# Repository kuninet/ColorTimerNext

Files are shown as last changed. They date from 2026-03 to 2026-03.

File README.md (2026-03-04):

# ColorTimer Next

ColorTimer の次期バージョンプロジェクトです。
IoTデバイス (ESP32) のボタンを押すことで、作業の開始・終了をクラウド（AWS）へ送信し、Webアプリでその履歴や統計情報を確認することができます。

## プロジェクトの目的と要件

本プロジェクトは以下の要件・前提のもとで開発を進めています。
詳細な機能要件、非機能要件については [要件.md](./docs/要件.md) を参照してください。

* **シンプルな実装**: テスト的に1台の機器からAWSにデータを送ることを想定しており、エッジ側もクラウド側も限りなくシンプルな設計・実装を行います。
* **限りなく無料枠**: 個人利用のためのプロジェクトであり、AWSの利用についてはAWS無料枠（Always Free / 12ヶ月無料枠）に全て収めることを目標としています。
* **オープンソース**: 本プロジェクトはオープンソース（OSS）として公開・管理します。そのため、シークレットや認証情報はコードに直書きせず、安全に管理する仕組みを取り入れています。
* **AIエージェントの活用**: 機能開発においてAIエージェントチームを活用しており、裏付け調査などのタスクには軽量なモデル（Gemini Flash等）を使用するルールで運用しています。

## リポジトリ構成 (予定)

* `/edge` : ESP32用プロジェクト（PlatformIOなどを用いたエッジ側のコード）
* `/backend` : AWSリソース構築用（AWS SAM / CDKなど構成）
* `/frontend` : Webアプリケーション（SPA等）

## ライセンス

[MIT License](LICENSE) (予定)

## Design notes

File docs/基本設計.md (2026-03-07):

# ColorTimer Next 基本設計

本ドキュメントでは、ColorTimer Nextプロジェクトのシステム全体像、インターフェース、データ構造について定義します。

## 1. システムアーキテクチャ構成
### 1.1 全体構成図 (概念)
```mermaid
flowchart LR
    A[ESP32 エッジデバイス]
    B[AWS API Gateway]
    C[AWS Lambda]
    D[(Amazon DynamoDB)]
    E[Webブラウザ<br/>PC/スマホ]
    F[S3 / CloudFront]

    A -- "Wi-Fi Manager<br/>(初期設定)" --> A
    A -- "HTTP POST<br/>(開始/終了)" --> B
    B --> C
    C -- "サーバー時刻付与" --> D
    
    F -- "SPA配信<br/>(Basic認証)" --> E
    E -- "HTTP GET<br/>(履歴取得)" --> B
```

### 1.2 各コンポーネントの役割
* **エッジ側 (ESP32-WROOM-32)**
  * **設定管理**: `WiFiManager` により初回起動時にAPになりブラウザから設定を行う。また、デバイスの**ボタンを押したまま電源を入れる（リセットする）**ことで、すべての設定（Wi-Fi、API情報等）を消去して工場出荷状態に戻す機能を実装する。
  * **状態遷移とUI**: ボタン押下をトリガーに「開始」「終了」状態を切り替え、OLEDへの状態表示、色LEDの切り替え、ブザー鳴動を行う。
  * **通信**: ステータス変更時にクラウドへ HTTPリクエスト を送信。エラー時はOLEDにエラー通知を行う。

* **クラウド側 (AWS バックエンド)**
  * **API Gateway**: データの受信用とWebアプリからの取得用の口を用意し、エッジからのリクエストはAPIキーで保護する（REST API と API Key の構成）。
  * **Lambda**: エッジからのリクエストを受け取り、**受信時のサーバー時刻**を付与してDynamoDBへ保存する。また、Webアプリからの履歴取得要求に対してDynamoDBからデータを取得し返却する。
  * **DynamoDB**: 時系列データとして安価に永続化する。

* **フロントエンド (Webアプリ)**
  * **アーキテクチャ**: React等のSPA (Single Page Application) をS3に配置し、CloudFront経由で配信する。
  * **認証**: CloudFront Functionsを用いたBasic認証でページへのアクセスを保護。
  * **機能**: API Gateway経由でLambdaからデータを取得し、作業履歴一覧および統計（週次・月次等）を表示する。

---

## 2. インターフェース設計 (REST API)

### 2.1 データ受信用 API (ESP32 -> AWS)
* **Endpoint**: `POST /api/logs`
* **認証**: HTTP Header `x-api-key: <ESP32に設定したAPIキー>`
* **Request Body (JSON)**:
  ```json
  {
    "device_id": "esp32-timer-01",
    "action": "start"  // "start" または "end"
  }
  ```
* **Response**:
  * 成功時: `200 OK`
  * 失敗時: `400 Bad Request`, `403 Forbidden`, `500 Internal Server Error`

### 2.2 データ取得用 API (Web App -> AWS)
* **Endpoint**: `GET /api/logs?device_id={device_id}&start_date={YYYY-MM-DD}&end_date={YYYY-MM-DD}`
* **認証**: Webアプリ側のセッションや事前発行トークン（Basic認証環境下での簡易なもの）を想定。
* **Response Body (JSON)**:
  ```json
  [
    {
      "timestamp": "2026-03-04T10:00:00Z",
      "action": "start"
    },
    ...
  ]
  ```

---

## 3. データベース設計 (DynamoDB テーブル定義)

永続化や集計のしやすさを考慮し、ログテーブルを以下のように設計する。
無料枠(25WCU/25RCU)に収めるため、プロビジョニングモードでミニマム構成とする想定。

| 項目論理名 | 項目物理名  | データ型 | キー設定 | 説明 |
| :--- | :--- | :--- | :--- | :--- |
| デバイスID | `DeviceId`  | String | **Partition Key (PK)** | リクエスト送信元のデバイスの識別子 |
| 送信日時 | `Timestamp` | String | **Sort Key (SK)** | ISO8601拡張形式（例: `2026-03-04T10:00:00.000Z`）。Lambdaで付与 |
| アクション | `Action` | String | - | "start" または "end" |
| 有効期限 | `ExpireAt`  | Number | (TTL属性) | DynamoDB TTL 用の Unix epoch 秒。Receiver Lambda で `LOG_RETENTION_DAYS` を元に付与する。 |

---

## 4. ハードウェア設計 (エッジデバイス)

本プロジェクトのエッジデバイスはメモリ・通信性能の安定性と将来の拡張性を考慮し、**ESP32-WROOM-32E** を採用します。

### 4.1 構成部品 (BOM)

| 部品名 | 仕様・想定パーツ | 数量 | 用途 |
| :--- | :--- | :--- | :--- |
| MCUボード | ESP32-WROOM-32E 開発ボード | 1 | メイン制御、Wi-Fi通信、HTTPSリクエスト通信 |
| ディスプレイ | 0.96インチ I2C OLED (SSD1306等) | 1 | 各種状態や通信エラーの表示 |
| フルカラーLED  | 砲弾型等RGB LED（または赤・青の単色LED2個） | 1 | 稼働状態の可視化。指定された「赤」「青」の点灯・点滅に使用 |
| 抵抗 | 330Ω（LED用）、10kΩ（スイッチ用） | 適宜 | 電流制限、外部プルアップ（必要に応じて）等 |
| タクトスイッチ | 汎用タクトスイッチ | 1 | 作業の「開始」「終了」を行うトリガーボタン |
| 圧電ブザー | パッシブブザー または アクティブブザー | 1 | 状態変更時（開始・終了・タイムアウト）の音通知 |

### 4.2 ピンアサインメント (GPIO割り当て案)

ESP32内でI2Cや各種出力として標準的かつ安全に利用可能な通信ピン・GPIOピンを割り当てます。

| コンポーネント | ポート/役割 | ESP32 GPIO  | 備考 |
| :--- | :--- | :--- | :--- |
| **OLED (I2C)** | SDA | **GPIO 21** | ESP32の標準I2Cデータピン |
| | SCL | **GPIO 22** | ESP32の標準I2Cクロックピン |
| **LED** | 赤色 (停止中) | **GPIO 25** | 出力利用に標準的で安全なGPIO |
| | 青色 (作業中) | **GPIO 26** | 出力利用に標準的で安全なGPIO |
| **ブザー** | 制御用 (PWM等)  | **GPIO 27** | 自由に出力として使えるGPIO |
| **スイッチ** | トリガー (入力) | **GPIO 33** | プログラム側で内部プルアップ(`INPUT_PULLUP`)を有効化して使用 |

> **Note**: 本表のアサインメントに従い、別途 `hardware/` などのディレクトリにてKiCadを使った物理的な基板設計・回路図作成をユーザー側で実施いただく進め方となります。

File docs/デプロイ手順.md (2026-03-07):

# デプロイ・構築手順

本ドキュメントでは、ColorTimer Nextプロジェクトの各コンポーネント（クラウド基盤・Webアプリ・エッジデバイス）のビルドから実環境へのデプロイ（書き込み）手順を記述します。
開発機材として、macOS および Windows 双方での操作を想定しています。

---

## 1. クラウド基盤のデプロイ (AWS SAM もしくは CDK想定)
**構成**: API Gateway + Lambda + DynamoDB

### 前提条件
- [AWS CLI](https://aws.amazon.com/jp/cli/) およびデプロイツール（[AWS SAM CLI](https://docs.aws.amazon.com/serverless-application-model/latest/developerguide/install-sam-cli.html) または Node.js + AWS CDK）がインストールされていること。
- `aws configure` コマンドで対象AWSアカウントのCredentials設定が完了していること。

### デプロイコマンド (SAM CLIの例)
```bash
# プロジェクトのルートディレクトリにいることを確認

# 推奨: 補助スクリプトでデプロイ
./scripts/aws/deploy-backend.sh

# ログ保持日数を変更する場合
./scripts/aws/deploy-backend.sh 30

# 環境変数で指定することも可能
LOG_RETENTION_DAYS=30 ./scripts/aws/deploy-backend.sh
```

手動で実行する場合:

```bash
cd backend
sam build
sam deploy --guided
sam deploy --parameter-overrides \
  BasicAuthValidAuths='["Basic <base64(username:password)>"]' \
  LogRetentionDays=365
```

---

## 2. Webアプリのデプロイ (フロントエンド)
**構成**: S3 (静的ホスティング) + CloudFront

### 前提条件
- Node.js (v18以降推奨) がインストールされていること。
- クラウド基盤側でデプロイされた S3バケット名 と CloudFrontの Distribution ID を確認していること。

### デプロイコマンド
作成済みの自動デプロイスクリプトを使用します。

```bash
# プロジェクトのルートディレクトリにいることを確認
# (フロントエンドのビルド、S3同期、CloudFrontのキャッシュクリアを自動で行います)
./scripts/aws/deploy-frontend.sh
```
*(※初回は backend 側がデプロイされ、S3バケットとCloudFrontディストリビューションが作成されている必要があります。)*

---

## 3. エッジデバイスの書き込み (ESP32)
**構成**: ESP32-WROOM-32 (PlatformIO での開発を想定)

### 前提条件
- VSCode および [PlatformIO IDE 拡張機能](https://platformio.org/install/ide?install=vscode) がインストールされていること。（CLI版の `pio` コマンドでも可）
- ESP32とPCがUSBケーブル(データ通信対応)で接続されていること。
- **Windows特有**: ESP32のUSBシリアル変換ドライバ (CP210x等) がインストールされ、デバイスマネージャーでCOMポートとして認識されていること。
- HTTPS の証明書検証のため、起動後に NTP で時刻同期できるインターネット接続があること。

### デプロイコマンド (PlatformIO Core CLI の例)
VSCode上からPlatformIOの「Upload」ボタン（右下の矢印アイコン）を押すのが最も簡単ですが、CLIで行う場合は以下となります。

```bash
# プロジェクトのエッジ側ディレクトリへ移動
cd edge

# 依存ライブラリのインストール・ビルド
pio run

# ESP32実機への書き込み
pio run -target upload

# (オプション) シリアルモニタを開いて動作確認・ログ確認
pio device monitor
```
- ※Windowsでは対象ポートが複数ある場合、上記コマンドで自動で認識されないことがあります。その場合は `pio run -t upload --upload-port COM3` のように明示的に指定してください。
- ※macOSでは `--upload-port /dev/cu.usbserial-*` のように指定できます。

---

## 4. 運用保守用スクリプトの実行（CloudFront Basic認証管理）
CloudFront Functions を利用したBasic認証のID/PWを管理・更新するためのスクリプトです。
認証情報は `backend/basic-auth-users.local.json` に保存され、このファイルは git 管理対象外です。

```bash
# プロジェクトのルートディレクトリにいることを確認

# ユーザー一覧に追加・更新する場合
./scripts/aws/manage-basic-auth.sh add <username> <password>

# ユーザーを削除する場合
./scripts/aws/manage-basic-auth.sh remove <username>

# 現在のユーザー一覧を確認する場合
./scripts/aws/manage-basic-auth.sh list

# SAM Parameter 用の JSON 配列だけ出力する場合
./scripts/aws/manage-basic-auth.sh print-parameter

# スクリプト実行後は backend デプロイスクリプトを使うと反映しやすいです
./scripts/aws/deploy-backend.sh

# 保持日数も同時に変える場合
./scripts/aws/deploy-backend.sh 30
```

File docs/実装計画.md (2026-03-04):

# 実装計画 (Issue分割予定一覧)

システムの構築を「クラウド基盤」「エッジ」「フロントエンド」の3つのフェーズに分け、以下の粒度でGitHub Issueを作成し、順次実装とPR（Pull Request）を進める計画とします。

## Phase 1: クラウド基盤 (AWS バックエンド)
このフェーズでは、AWS上にAPIとデータベースを構築し、ローカルやPostman等で単体テストが通る状態を目指します。

* **Issue 1**: [Infra] AWSバックエンドリソースのコード化（SAM等）および DynamoDBテーブルの作成
* **Issue 2**: [Backend] ステータスデータ受信用機能 (API Gateway + Lambda) の実装とローカル単体テスト・モックテストの作成
* **Issue 3**: [Backend] データ取得用API (API Gateway + Lambda) の実装と単体テスト・CORS設定

## Phase 2: エッジデバイス (ESP32)
APIのインターフェースが固まった状態で、実際にデバイスからの通信とハードウェア制御を組み込みます。

* **Issue 4**: [Edge] PlatformIOプロジェクトの初期化と、`WiFiManager` を用いたAPモード・ブラウザ設定(Wi-Fi・APIキー・タイムアウト等)の実装
* **Issue 5**: [Edge] ハードウェア制御 (物理ボタンによる状態切替、フルカラーLED制御、ブザー鳴動、OLEDディスプレイへの状態表示) の実装
* **Issue 6**: [Edge] AWS APIへのHTTP POST送信処理と、エラー時（未接続・送信失敗）のOLEDエラー表示・ハンドリングの実装

## Phase 3: フロントエンド (Webアプリケーション)
クラウドのAPIからデータを取り出し、描画と集計を行うSPAを構築します。

* **Issue 7**: [Frontend] React(Vite等)プロジェクトの初期化と、S3+CloudFrontへの静的デプロイパイプライン（手動コマンド等）の準備
* **Issue 8**: [Frontend/Infra] CloudFront Functions を用いたサイト全体のBasic認証の実装と、簡易なID/PW管理用シェルスクリプトの作成
* **Issue 9**: [Frontend] 作業履歴・ログの一覧表示画面（API連携）の実装
* **Issue 10**: [Frontend] 作業ログに基づく週次・月次の稼働状況・統計表示画面の実装

---
本計画に基づいて順番にIssueを作成し、実装・レビュー（ユーザー確認）・マージのサイクルを回して開発を進めます。

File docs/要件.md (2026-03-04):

# ColorTimer Next 要件

## 概要
* ColorTimerの次期バージョンを開発する。
* **プロジェクトの前提**
  * 1台の機器からテスト的にAWSにデータを送ることを想定。
  * エッジ側もクラウド側も**限りなくシンプルな実装**にする。
  * AWSの利用料金は**限りなく無料枠に納める**ことを目標にする。
  * プロジェクトは**オープンソースハードウェア/ソフトウェアとしてGitHubで公開・管理**する。シークレット情報の取り扱いには注意する。
  * 【エージェント開発ルール】調査などのタスクメンバ作業は「Gemini Flash」などの軽量モデルで実施する（今後の他プロジェクトも共通）。

## 要件
### 機能要件
* エッジ側
  * Color Timerのエッジ部分はESP32-WROOM-32を使用する。
    * [[116108]ESP32-WROOM-32Eマイコンボード](https://akizukidenshi.com/catalog/g/g116108/)
  * トリガーボタンを押すと、「作業開始」「作業終了」をクラウドへ送信する。
  * 本体にはLED2つ装備
    * 赤LED - 作業してない
    * 青LED - 作業中(設定したタイムアウト時間が来ると点滅してお知らせ。自動終了はせず、ユーザーのボタン操作で終了イベントを送信する)
  * OLEDディスプレイに現在の状況を表示
    * 起動完了
    * 作業開始
    * 作業終了
    * タイムアウト
    * エラー（Wi-Fi未接続やAWS送信エラーが発生した場合）
  * 圧電ブザーで作業開始、タイムアウト、作業終了を通知
  * **ネットワーク接続・初期設定**: 
    * 初期起動時はマイコンがアクセスポイント(AP)として動作する。
    * PCやスマートフォンのブラウザからアクセスし、Wi-Fi設定（SSID/パスワード）や各設定値（タイムアウト値など）を設定可能にする。

* クラウド側
  * データ受信のアーキテクチャ
    * **API Gateway (HTTP API) + Lambda** 構成で受信する。（AWS IoT Core等のような複雑な証明書管理は避け、ESP32からのHTTPリクエストでシンプルに受信する）
  * 受信した「作業開始」「作業終了」の日時を永続化する。
    * クラウド側での受信時刻をタイムスタンプとする。（エッジ側では時刻を持たず、「開始」「終了」のイベント種別のみを送信する）
    * ストレージには **DynamoDB**（オンデマンド または プロビジョニング25WCU/25RCUの無料枠内）を使用する。
  * Webアプリ
    * 作業履歴の一覧表示できるようにしたい。
    * 統計表示（週次、月次の稼働状況）を見えるようにしたい。
    * ホスティングは **S3静的ホスティング + CloudFront** のSPA構成とする。

### 非機能要件
* セキュリティ対策
  * 最低限のセキュリティはかけたい。AWSにいたずらされない程度の対策をしたい。軽く機器認証はしたい。
    * API Gatewayの **APIキー** を利用して、エッジ側からのリクエストを簡易認証する。
  * Webアプリを使えるIDを限定したい。アプリID管理はあまり複雑になりすぎない程度で。
    * Cognito等の複雑な構成は避け、**CloudFront Functionsを使ったBasic認証** で保護する。
    * ※ 運用保守用として、パスワード変更やID/PW追加ができる簡易なシェルスクリプトを別途用意する。
  * **OSS対応**: 認証情報や設定値などは.env等で管理し、リポジトリには含めない。

* パフォーマンス
  * 当初は1台程度の負荷を想定。

* 可用性
  * 個人使用なので、可用性要件なし。

* コスト
  * AWSのサービスを活用するが、なるべく安価にしたい。無料枠にすべて収まるのが理想。

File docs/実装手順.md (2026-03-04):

# 実装手順

## 進め方
* githubリポジトリ(公開)を作成
* 設計文書、実装計画文書を作成して、承認を取る
* 実装計画に基づいて、githubにissueを作成して、順番に実装する
* issueが実装計画と合っているか確認して承認を取る
* issueごとにブランチを作成して実装を開始して、実装完了ごとに承認をとり、承認されたらPRを作成してマージする。
* **[追加提案]** PR作成時はIssue番号を紐付け（`Fixes #Issue番号` 等）、マージ時にIssueが自動クローズされるようにする。
* **[追加提案]** 実装の完了・マージに合わせて、システム構成や設計に変更があった場合は `README.md` や設計ドキュメントを忘れずに更新する。
* **[追加提案]** 必要に応じて、PR作成時に静的解析（Lint等）が走るCI環境（GitHub Actions等）を設定し、品質を担保する。
* **[追加提案]** クラウド側（LambdaやAPI等）の実装においては、デプロイ前にパソコン上（ローカル環境）で単体テストやモックを利用したテストを実行・検証できる設計とし、実装と並行してテストコードを作成する。

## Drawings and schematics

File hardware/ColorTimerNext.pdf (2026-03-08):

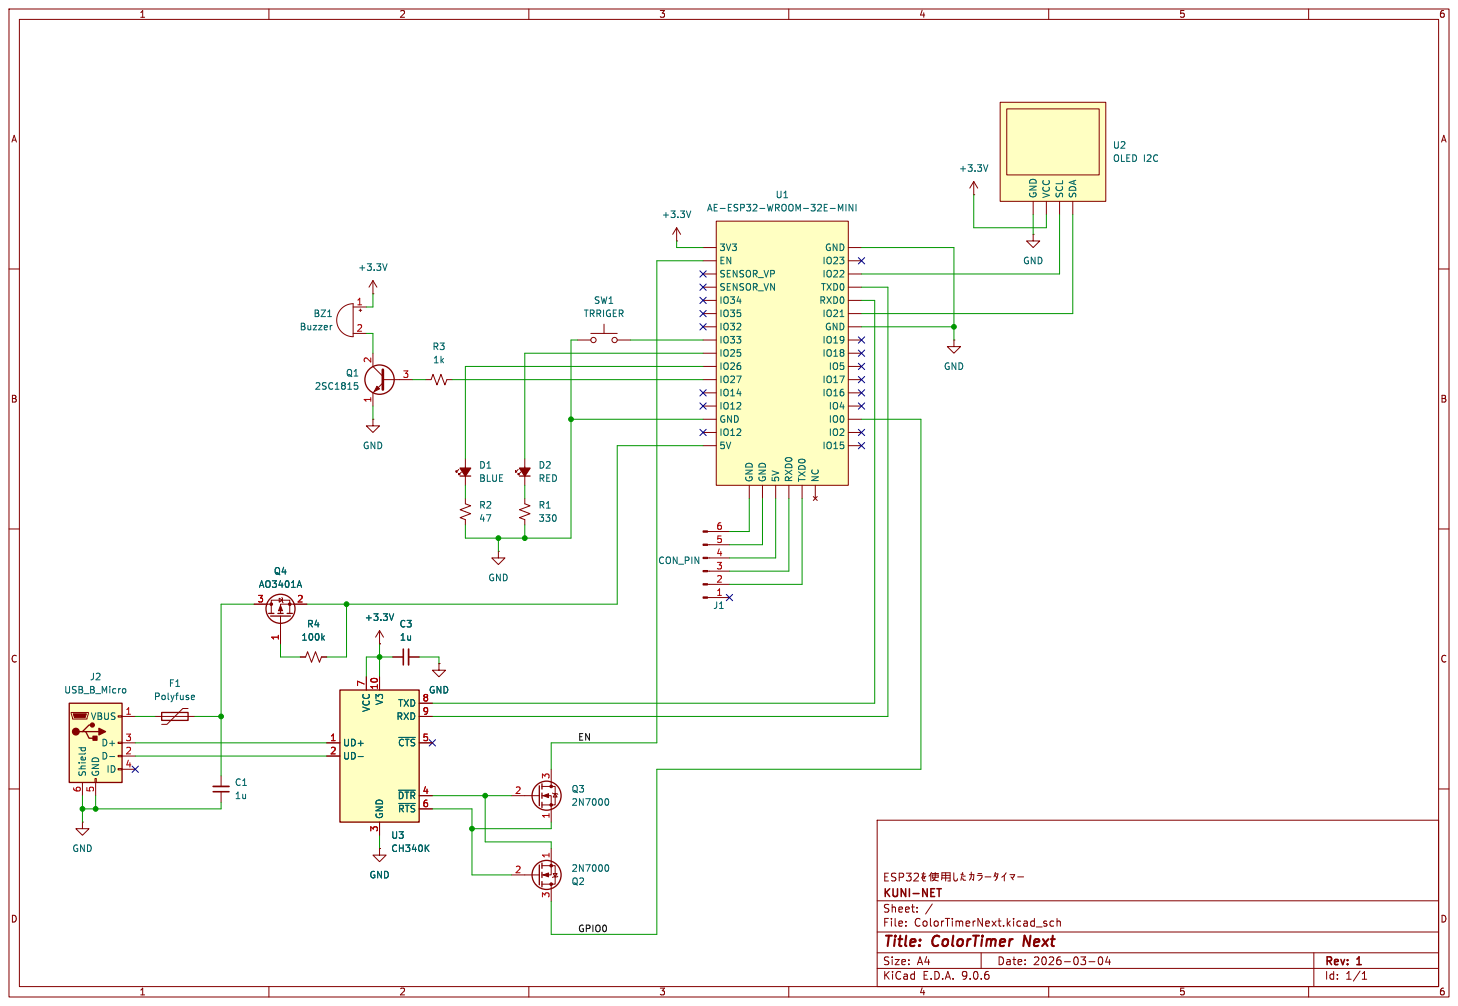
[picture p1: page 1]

3 TXD 8 RXD 9 ~{CTS}5 ~{DTR}4 ~{RTS}6 U3 CH340K GND GND VCC SCL SDA U2 OLED I2C

3 TXD 8 RXD 9 ~{CTS}5 ~{DTR}4 ~{RTS}6 +3.3V C3

Id: 1/1 Title: ColorTimer Next File: ColorTimerNext.kicad_sch Sheet: / KUNI-NET

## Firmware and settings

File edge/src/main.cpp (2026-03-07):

#include "HardwareConfig.h"
#include <Arduino.h>
#include <ArduinoJson.h>
#include <Bounce2.h>
#include <HTTPClient.h>
#include <Preferences.h>
#include <WiFiClientSecure.h>
#include <WiFiManager.h>
#include <time.h>

Preferences preferences;

// Preferencesの名前空間とキー名
const char *PREF_NAMESPACE = "colortimer";
const char *PREF_DEVICE_ID = "device_id";
const char *PREF_API_ENDPOINT = "api_endpt";
const char *PREF_API_KEY = "api_key";
const char *PREF_TIMEOUT_MIN = "timeout_min";

// メモリ保持用変数 (初期値)
char deviceId[32] = "esp32-timer-default";
char apiEndpoint[128] =
    "https://********.execute-api.ap-northeast-1.amazonaws.com/prod/api/logs";
char apiKey[64] = "your_api_key_here";
char timeoutMin[8] = "30"; // デフォルト30分

bool shouldSaveConfig = false;
bool systemTimeSynchronized = false;

const char *NTP_PRIMARY_SERVER = "time.aws.com";
const char *NTP_SECONDARY_SERVER = "pool.ntp.org";
const char *NTP_TERTIARY_SERVER = "ntp.nict.jp";
constexpr time_t MIN_VALID_UNIX_TIME = 1704067200; // 2024-01-01T00:00:00Z
constexpr unsigned long TIME_SYNC_TIMEOUT_MS = 15000;
constexpr unsigned long TIME_SYNC_POLL_INTERVAL_MS = 250;
constexpr unsigned long TLS_HANDSHAKE_TIMEOUT_SEC = 15;

// Amazon Root CA 1 for execute-api.*.amazonaws.com certificates.
const char *AWS_ROOT_CA = R"CERT(
-----BEGIN CERTIFICATE-----
MIIDQTCCAimgAwIBAgITBmyfz5m/jAo54vB4ikPmljZbyjANBgkqhkiG9w0BAQsF
ADA5MQswCQYDVQQGEwJVUzEPMA0GA1UEChMGQW1hem9uMRkwFwYDVQQDExBBbWF6
b24gUm9vdCBDQSAxMB4XDTE1MDUyNjAwMDAwMFoXDTM4MDExNzAwMDAwMFowOTEL
MAkGA1UEBhMCVVMxDzANBgNVBAoTBkFtYXpvbjEZMBcGA1UEAxMQQW1hem9uIFJv
b3QgQ0EgMTCCASIwDQYJKoZIhvcNAQEBBQADggEPADCCAQoCggEBALJ4gHHKeNXj
ca9HgFB0fW7Y14h29Jlo91ghYPl0hAEvrAIthtOgQ3pOsqTQNroBvo3bSMgHFzZM
9O6II8c+6zf1tRn4SWiw3te5djgdYZ6k/oI2peVKVuRF4fn9tBb6dNqcmzU5L/qw
IFAGbHrQgLKm+a/sRxmPUDgH3KKHOVj4utWp+UhnMJbulHheb4mjUcAwhmahRWa6
VOujw5H5SNz/0egwLX0tdHA114gk957EWW67c4cX8jJGKLhD+rcdqsq08p8kDi1L
93FcXmn/6pUCyziKrlA4b9v7LWIbxcceVOF34GfID5yHI9Y/QCB/IIDEgEw+OyQm
jgSubJrIqg0CAwEAAaNCMEAwDwYDVR0TAQH/BAUwAwEB/zAOBgNVHQ8BAf8EBAMC
AYYwHQYDVR0OBBYEFIQYzIU07LwMlJQuCFmcx7IQTgoIMA0GCSqGSIb3DQEBCwUA
A4IBAQCY8jdaQZChGsV2USggNiMOruYou6r4lK5IpDB/G/wkjUu0yKGX9rbxenDI
U5PMCCjjmCXPI6T53iHTfIUJrU6adTrCC2qJeHZERxhlbI1Bjjt/msv0tadQ1wUs
N+gDS63pYaACbvXy8MWy7Vu33PqUXHeeE6V/Uq2V8viTO96LXFvKWlJbYK8U90vv
o/ufQJVtMVT8QtPHRh8jrdkPSHCa2XV4cdFyQzR1bldZwgJcJmApzyMZFo6IQ6XU
5MsI+yMRQ+hDKXJioaldXgjUkK642M4UwtBV8ob2xJNDd2ZhwLnoQdeXeGADbkpy
rqXRfboQnoZsG4q5WTP468SQvvG5
-----END CERTIFICATE-----
)CERT";

// 稼働ステート管理
enum TimerState { STATE_STANDBY, STATE_RUNNING, STATE_TIMEOUT };
TimerState currentState = STATE_STANDBY;

// 長押し機能やタイムアウト計算用
unsigned long stateStartTime = 0;

// ボタンのデバウンス用インスタンス
Bounce debouncer = Bounce();

bool hasValidSystemTime() { return time(nullptr) >= MIN_VALID_UNIX_TIME; }

bool ensureSystemTimeSync() {
  if (systemTimeSynchronized && hasValidSystemTime()) {
    return true;
  }

  Serial.println("Synchronizing system clock for TLS validation...");
  configTime(0, 0, NTP_PRIMARY_SERVER, NTP_SECONDARY_SERVER, NTP_TERTIARY_SERVER);

  const unsigned long startedAt = millis();
  while (millis() - startedAt < TIME_SYNC_TIMEOUT_MS) {
    if (hasValidSystemTime()) {
      systemTimeSynchronized = true;
      Serial.printf("System time synchronized: %ld\n",
                    static_cast<long>(time(nullptr)));
      return true;
    }
    delay(TIME_SYNC_POLL_INTERVAL_MS);
  }

  Serial.println("Failed to synchronize system clock; TLS connection aborted.");
  return false;
}

void clearStoredSettings(WiFiManager &wm) {
  preferences.clear();
  wm.resetSettings();
}

// WiFiManagerの設定が保存された際に呼ばれるコールバック
void saveConfigCallback() {
  Serial.println("Should save config");
  shouldSaveConfig = true;
}

// API通信関数 (戻り値: 成功なら true)
bool sendLogToApi(const char *action) {
  if (WiFi.status() != WL_CONNECTED) {
    Serial.println("Error: WiFi not connected");
    return false;
  }

  if (!ensureSystemTimeSync()) {
    return false;
  }

  WiFiClientSecure *client = new WiFiClientSecure;
  if (client) {
    client->setCACert(AWS_ROOT_CA);
    client->setHandshakeTimeout(TLS_HANDSHAKE_TIMEOUT_SEC);
  } else {
    Serial.println("Failed to create secure client");
    return false;
  }

  HTTPClient https;

  Serial.print("Connecting to API: ");
  Serial.println(apiEndpoint);

  if (https.begin(*client, apiEndpoint)) {
    // APIヘッダーの追加
    https.addHeader("Content-Type", "application/json");
    https.addHeader("x-api-key", apiKey);

    // JSONペイロードの生成
    JsonDocument doc;
    doc["device_id"] = deviceId;
    doc["action"] = action;
    String requestBody;
    serializeJson(doc, requestBody);

    Serial.print("Sending POST request: ");
    Serial.println(requestBody);

    // POST送信
    int httpCode = https.POST(requestBody);

    bool success = false;
    if (httpCode > 0) {
      Serial.printf("HTTP Response code: %d\n", httpCode);
      if (httpCode == HTTP_CODE_OK || httpCode == HTTP_CODE_CREATED) {
        // String payload = https.getString();
        // Serial.println(payload);
        success = true;
      }
    } else {
      Serial.printf("HTTP Request failed, error: %s\n",
                    https.errorToString(httpCode).c_str());
    }

    https.end();
    delete client;
    return success;
  } else {
    Serial.println("Unable to connect to HTTPS endpoint");
    delete client;
    return false;
  }
}

void setup() {
  Serial.begin(115200);
  Serial.println("\n\nStarting ColorTimer Next...");

  // ハードウェアピン等の初期化 (OLED, LED, Buzzer)
  initHardware();

  // 初期化リセット用ボタンの設定とBounce2へのアタッチ
  debouncer.attach(BUTTON_PIN, INPUT_PULLUP);
  debouncer.interval(25); // 25msのデバウンス

  // Preferencesの初期化 (読み書きモード)
  preferences.begin(PREF_NAMESPACE, false);

  // WiFiManagerのインスタンス生成
  WiFiManager wm;
  wm.setSaveConfigCallback(saveConfigCallback);

  // 起動時にボタン(GPIO33)がLOW(押されている状態)なら設定を初期化する
  debouncer.update();
  if (debouncer.read() == LOW) {
    displayStatus("RESETTING", "Clearing Settings");
    Serial.println("Reset button is pressed! Clearing all settings...");
    playBeep(500);
    clearStoredSettings(wm);
    displayStatus("CLEARED", "Please Reboot.");
    Serial.println(
        "Settings cleared. Please connect to 'ColorTimer-AP' to reconfigure.");
    while (true) {
      delay(100);
    } // 停止
  }

  // フラッシュメモリからの設定読み出し
  String savedDeviceId = preferences.getString(PREF_DEVICE_ID, deviceId);
  String savedApiEndpoint =
      preferences.getString(PREF_API_ENDPOINT, apiEndpoint);
  String savedApiKey = preferences.getString(PREF_API_KEY, apiKey);
  String savedTimeoutMin = preferences.getString(PREF_TIMEOUT_MIN, timeoutMin);

  strlcpy(deviceId, savedDeviceId.c_str(), sizeof(deviceId));
  strlcpy(apiEndpoint, savedApiEndpoint.c_str(), sizeof(apiEndpoint));
  strlcpy(apiKey, savedApiKey.c_str(), sizeof(apiKey));
  strlcpy(timeoutMin, savedTimeoutMin.c_str(), sizeof(timeoutMin));

  // カスタムパラメータの設定
  WiFiManagerParameter custom_device_id("device_id", "Device ID", deviceId, 32);
  WiFiManagerParameter custom_api_endpoint("api_endpoint", "API Endpoint URL",
                                           apiEndpoint, 128);
  WiFiManagerParameter custom_api_key("api_key", "API Gateway Key", apiKey, 64);
  WiFiManagerParameter custom_timeout_min("timeout_min", "Timeout (minutes)",
                                          timeoutMin, 8);

  wm.addParameter(&custom_device_id);
  wm.addParameter(&custom_api_endpoint);
  wm.addParameter(&custom_api_key);
  wm.addParameter(&custom_timeout_min);

  displayStatus("Wi-Fi Setup", "Connecting...");

  // Wi-Fi接続の試行。接続情報がないか失敗した場合はColorTimer-APというアクセスポイントを起動する
  if (!wm.autoConnect("ColorTimer-AP", "password")) {
    displayError("Wi-Fi Failed");
    Serial.println("Failed to connect and hit timeout");
    playErrorSound();
    delay(3000);
    ESP.restart();
  }

  // 設定ポータルでSaveされた場合、新たな値をフラッシュメモリに保存
  if (shouldSaveConfig) {
    strlcpy(deviceId, custom_device_id.getValue(), sizeof(deviceId));
    strlcpy(apiEndpoint, custom_api_endpoint.getValue(), sizeof(apiEndpoint));
    strlcpy(apiKey, custom_api_key.getValue(), sizeof(apiKey));
    strlcpy(timeoutMin, custom_timeout_min.getValue(), sizeof(timeoutMin));

    preferences.putString(PREF_DEVICE_ID, deviceId);
    preferences.putString(PREF_API_ENDPOINT, apiEndpoint);
    preferences.putString(PREF_API_KEY, apiKey);
    preferences.putString(PREF_TIMEOUT_MIN, timeoutMin);

    Serial.println("Configuration saved to Preferences.");
  }

  Serial.println("\nConnected to Wi-Fi!");
  if (!ensureSystemTimeSync()) {
    Serial.println("Warning: time sync did not complete during setup.");
  }
  displayStatus("Connected!");
  playBeep(100);
  delay(100);
  playBeep(100);

  // 初期ステート: Standby
  currentState = STATE_STANDBY;
  setLedState(LED_RED); // 待機＝赤点灯
  displayStatus("STANDBY", "Ready to Start");
  displayStatus("STANDBY", "Ready to Start");
}

void loop() {
  // LEDの点滅更新
  updateLedBlink();

  // 5秒ごとに現在のステータスをシリアルへ出力
  static unsigned long lastStatusLog = 0;
  if (millis() - lastStatusLog >= 5000) {
    lastStatusLog = millis();
    if (currentState == STATE_RUNNING) {
      Serial.println("[STATUS] 状態: 作業中 (RUNNING) | LED: 青点灯");
    } else if (currentState == STATE_TIMEOUT) {
      Serial.println(
          "[STATUS] 状態: タイムアウト (TIMEOUT) | LED: 青点滅 & アラーム");
    } else {
      Serial.println("[STATUS] 状態: 休み中 (STANDBY) | LED: 赤点灯");
    }
  }

  // タイムアウト検知処理
  if (currentState == STATE_RUNNING) {
    long timeoutMs = atol(timeoutMin) * 60 * 1000;
    if (millis() - stateStartTime >= timeoutMs) {
      currentState = STATE_TIMEOUT;
      setLedState(LED_BLUE_BLINK); // タイムアウト＝青点滅
      displayStatus("TIMEOUT", "Time's up!");
      Serial.println("[Action] Timer Timeout Reached");
    }
  }

  // タイムアウト状態ならカラータイマー音を非同期で鳴らす
  if (currentState == STATE_TIMEOUT) {
    playColorTimerSound();
  }

  // ボタンの状態を更新
  debouncer.update();

  static unsigned long buttonPressStartTime = 0;
  static bool beep3sDone = false;
  static bool beep5sDone = false;

  // ボタンが押された（立ち下がりエッジ）時の処理
  if (debouncer.fell()) {
    buttonPressStartTime = millis();
    beep3sDone = false;
    beep5sDone = false;
  }

  // ボタンが押されている間の処理（長押し検知・ビープ音鳴動）
  if (!debouncer.read()) { // !HIGH (LOW)
                           // の時、ボタンが押されていると仮定(INPUT_PULLUP)
    if (buttonPressStartTime > 0) {
      unsigned long pressedDuration = millis() - buttonPressStartTime;
      // 3秒経過
      if (pressedDuration >= 3000 && pressedDuration < 5000 && !beep3sDone) {
        playBeep(100); // 3秒ピッ
        displayStatus("Hold: 3s", "Release for AP");
        beep3sDone = true;
      }
      // 5秒経過
      else if (pressedDuration >= 5000 && !beep5sDone) {
        playBeep(100);
        delay(100);
        playBeep(100); // 5秒ピピッ
        displayStatus("Hold: 5s", "Release to Reset");
        beep5sDone = true;
      }
    }
  }

  // ボタンが離された（立ち上がりエッジ）時の処理
  if (debouncer.rose()) {
    unsigned long pressedDuration = millis() - buttonPressStartTime;
    buttonPressStartTime = 0;

    if (pressedDuration >= 5000) {
      // 5秒以上長押し -> 完全初期化
      Serial.println("[Action] Reset to default settings");
      displayStatus("RESETTING", "Clearing Settings");
      WiFiManager wm;
      clearStoredSettings(wm);
      Serial.println(
          "[Action] Settings cleared. Restarting into initial setup state.");
      delay(1000);
      ESP.restart(); // 再起動して初期状態へ
    } else if (pressedDuration >= 3000) {
      // 3秒〜5秒長押し -> 設定ポータル起動（オンデマンドAP）
      Serial.println("[Action] Starting Config Portal...");
      displayStatus("CONFIG MODE", "Connect to AP");
      setLedState(LED_BLUE_BLINK); // 設定モード中は青点滅

      WiFiManager wm;

      // 保存時に shouldSaveConfig が呼ばれるようにセット
      wm.setSaveConfigCallback(saveConfigCallback);
      shouldSaveConfig = false; // 初期化しておく

      // Saveボタン押下後、WiFi接続試行の完了を待たずに強制的にポータルを抜ける
      wm.setBreakAfterConfig(true);

      // カスタムパラメータを再セットしてAP開始
      WiFiManagerParameter custom_device_id("device_id", "Device ID", deviceId,
                                            32);
      WiFiManagerParameter custom_api_endpoint(
          "api_endpoint", "API Endpoint URL", apiEndpoint, 128);
      WiFiManagerParameter custom_api_key("api_key", "API Gateway Key", apiKey,
                                          64);
      WiFiManagerParameter custom_timeout_min(
          "timeout_min", "Timeout (minutes)", timeoutMin, 8);
      wm.addParameter(&custom_device_id);
      wm.addParameter(&custom_api_endpoint);
      wm.addParameter(&custom_api_key);
      wm.addParameter(&custom_timeout_min);

      // ポータル開始 (Break設定により必ずfalseで戻るか抜ける)
      wm.startConfigPortal("ColorTimer-AP");

      // 保存ボタンが押され、ポータルを抜けた場合はここに来る
      if (shouldSaveConfig) {
        strlcpy(deviceId, custom_device_id.getValue(), sizeof(deviceId));
        strlcpy(apiEndpoint, custom_api_endpoint.getValue(),
                sizeof(apiEndpoint));
        strlcpy(apiKey, custom_api_key.getValue(), sizeof(apiKey));
        strlcpy(timeoutMin, custom_timeout_min.getValue(), sizeof(timeoutMin));

        // グローバルのpreferencesは既にbegin()されているのでそのまま書き込む
        preferences.putString(PREF_DEVICE_ID, deviceId);
        preferences.putString(PREF_API_ENDPOINT, apiEndpoint);
        preferences.putString(PREF_API_KEY, apiKey);
        preferences.putString(PREF_TIMEOUT_MIN, timeoutMin);
        shouldSaveConfig = false;

        Serial.println("[Action] Updated settings, restarting...");
        displayStatus("SAVED", "Restarting...");
      } else {
        Serial.println(
            "[Action] Config portal closed without saving, restarting...");
        displayStatus("CANCELED", "Restarting...");
      }
      delay(1000);
      ESP.restart();
    } else {
      // --- 短押し (3秒未満) の場合は本来のAPI通信処理 ---
      if (currentState == STATE_STANDBY) {
        // Standby -> Running (Start API Request)
        displayStatus("Sending...", "Start Timer");
        if (sendLogToApi("start")) {
          currentState = STATE_RUNNING;
          stateStartTime = millis(); // 開始時間を記録
          setLedState(LED_BLUE);     // 作業中＝青点灯
          displayStatus("RUNNING", "Working...");
          playBeep(200); // 成功音ピッ
          Serial.println("[Action] Timer Started");
        } else {
          displayError("API Send Failed");
          playErrorSound();
          delay(2000);
          displayStatus("STANDBY", "Ready to Start");
        }

      } else if (currentState == STATE_RUNNING ||
                 currentState == STATE_TIMEOUT) {
        // Running/Timeout -> Standby (Stop API Request)
        displayStatus("Sending...", "Stop Timer");
        if (sendLogToApi("stop")) {
          currentState = STATE_STANDBY;
          setLedState(LED_RED); // 待機＝赤点灯に戻る
          displayStatus("STANDBY", "Task Stopped.");
          playBeep(100);
          delay(100);
          playBeep(100); // 終了音ピピッ
          Serial.println("[Action] Timer Stopped");
        } else {
          displayError("API Send Failed");
          playErrorSound();
          delay(2000);
          displayStatus("RUNNING", "Working...");
        }
      }
    }
  }

  delay(10);
}

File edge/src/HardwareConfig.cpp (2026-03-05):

#include "HardwareConfig.h"
#include <Adafruit_GFX.h>
#include <Adafruit_SSD1306.h>
#include <Wire.h>

#define SCREEN_WIDTH 128
#define SCREEN_HEIGHT 64
#define OLED_RESET -1 // Reset pin # (or -1 if sharing Arduino reset pin)

Adafruit_SSD1306 display(SCREEN_WIDTH, SCREEN_HEIGHT, &Wire, OLED_RESET);

// State internally used for blinking led
static LedColor currentLedState = LED_OFF;
static unsigned long lastBlinkTime = 0;
static bool ledToggleState = false;

void initHardware() {
  // Initialize I2C for OLED
  Wire.begin(I2C_SDA_PIN, I2C_SCL_PIN);
  if (!display.begin(SSD1306_SWITCHCAPVCC, 0x3C)) {
    Serial.println(F("SSD1306 allocation failed"));
    // Try to proceed anyway
  } else {
    display.clearDisplay();
    display.setTextSize(1);
    display.setTextColor(SSD1306_WHITE);
    display.setCursor(0, 0);
    display.println("Initializing...");
    display.display();
  }

  // Initialize LEDs
  pinMode(LED_RED_PIN, OUTPUT);
  pinMode(LED_BLUE_PIN, OUTPUT);
  digitalWrite(LED_RED_PIN, LOW);
  digitalWrite(LED_BLUE_PIN, LOW);

  // Initialize Buzzer via PWM (ledc mechanism in ESP32)
  ledcSetup(BUZZER_CHANNEL, BUZZER_FREQ, BUZZER_RES);
  ledcAttachPin(BUZZER_PIN, BUZZER_CHANNEL);
  ledcWrite(BUZZER_CHANNEL, 0); // Keep quiet initially
}

void displayStatus(const char *statusStr, const char *detailStr) {
  display.clearDisplay();

  display.setTextSize(2);
  display.setTextColor(SSD1306_WHITE);
  display.setCursor(0, 5);
  display.println(statusStr);

  if (detailStr && strlen(detailStr) > 0) {
    display.setTextSize(1);
    display.setCursor(0, 30);
    display.println(detailStr);
  }

  display.display();
}

void displayError(const char *errorStr) {
  display.clearDisplay();
  display.setTextSize(1);
  display.setTextColor(SSD1306_WHITE);
  display.setCursor(0, 0);
  display.println("--- ERROR ---");
  display.setCursor(0, 20);
  display.println(errorStr);
  display.display();
}

void setLedState(LedColor color) {
  currentLedState = color;
  digitalWrite(LED_RED_PIN, LOW);
  digitalWrite(LED_BLUE_PIN, LOW);

  switch (color) {
  case LED_RED:
    digitalWrite(LED_RED_PIN, HIGH);
    break;
  case LED_BLUE:
    digitalWrite(LED_BLUE_PIN, HIGH);
    break;
  case LED_BLUE_BLINK:
    digitalWrite(LED_BLUE_PIN, HIGH);
    ledToggleState = true;
    lastBlinkTime = millis();
    break;
  case LED_RED_BLINK:
    digitalWrite(LED_RED_PIN, HIGH);
    ledToggleState = true;
    lastBlinkTime = millis();
    break;
  default:
    break;
  }
}

void updateLedBlink() {
  if (currentLedState == LED_BLUE_BLINK) {
    if (millis() - lastBlinkTime >= 500) { // Toggle every 500ms
      lastBlinkTime = millis();
      ledToggleState = !ledToggleState;
      digitalWrite(LED_BLUE_PIN, ledToggleState ? HIGH : LOW);
    }
  } else if (currentLedState == LED_RED_BLINK) {
    if (millis() - lastBlinkTime >= 250) { // Toggle faster (250ms)
      lastBlinkTime = millis();
      ledToggleState = !ledToggleState;
      digitalWrite(LED_RED_PIN, ledToggleState ? HIGH : LOW);
    }
  }
}

void playBeep(int durationMs) {
  ledcWrite(BUZZER_CHANNEL, 128); // 50% duty cycle
  delay(durationMs);
  ledcWrite(BUZZER_CHANNEL, 0);
}

void playErrorSound() {
  for (int i = 0; i < 3; i++) {
    playBeep(100);
    delay(100);
  }
}

// タイムアウト時のカラータイマー音（徐々に早くなる）
// ※ 呼び出し元で delay
// を挟まないよう、内部で時間を管理して1回分の「ピコン」を鳴らすか判定
void playColorTimerSound() {
  static unsigned long lastSoundTime = 0;
  static int beepInterval = 1000; // 初期インターバル(ms)
  static int beepCount = 0;

  if (millis() - lastSoundTime >= beepInterval) {
    lastSoundTime = millis();

    // ピ・コン (高低音)
    ledcWriteTone(BUZZER_CHANNEL, 1500); // 高音
    delay(100);
    ledcWriteTone(BUZZER_CHANNEL, 1000); // 低音
    delay(150);
    ledcWrite(BUZZER_CHANNEL, 0); // 停止
    // 元の周波数にリセット
    ledcSetup(BUZZER_CHANNEL, BUZZER_FREQ, BUZZER_RES);

    beepCount++;

    // だんだん早くする（最小200msまで）
    if (beepCount % 5 == 0 && beepInterval > 200) {
      beepInterval -= 150;
    }
  }
}

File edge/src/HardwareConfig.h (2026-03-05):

#ifndef HARDWARE_CONFIG_H
#define HARDWARE_CONFIG_H

#include <Arduino.h>

// GPIO Definitions (based on target design)
#define I2C_SDA_PIN 21
#define I2C_SCL_PIN 22
#define LED_RED_PIN 25
#define LED_BLUE_PIN 26
#define BUZZER_PIN 27
#define BUTTON_PIN 33

// PWM Configuration for Buzzer
#define BUZZER_CHANNEL 0
#define BUZZER_FREQ 2000
#define BUZZER_RES 8

void initHardware();

// OLED Display Functions
void displayStatus(const char *statusStr, const char *detailStr = "");
void displayError(const char *errorStr);

// LED Functions
enum LedColor { LED_OFF, LED_RED, LED_BLUE, LED_BLUE_BLINK, LED_RED_BLINK };
void setLedState(LedColor color);
void updateLedBlink(); // Call this in loop()

// Buzzer Functions
void playBeep(int durationMs);
void playErrorSound();
void playColorTimerSound(); // タイムアウト用カラータイマー音

#endif

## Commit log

2026-03-04 docs: 初回コミット（要件定義、README、初期手順書）
2026-03-04 docs: 追加課題への回答を反映（タイムアウト、エラー処理、統計）
    [課題.csv]
2026-03-04 docs: 基本設計と実装計画（Issue一覧）の作成
2026-03-04 docs: 基本設計図をMermaid形式に修正
2026-03-04 docs: ESP32-WROOM-32E向けハードウェア設計（BOM・ピンアサイン）を追記
2026-03-04 fix: [Issue 3 review] remove TTL to keep logs eternally and update design doc
    [ColorTimerNext.kicad_pcb, ColorTimerNext.kicad_sch]
2026-03-04 feat: [Issue 7] Implement ESP32 project initialization and WiFiManager portal
    [main.cpp]
2026-03-04 feat: [Issue 7 review] Add hardware reset logic via BUTTON_PIN to clear WiFi/Preferences
    [main.cpp]
2026-03-04 feat: [Issue 9] Implement hardware peripherals control (OLED, LED, Buzzer, Button)
    [HardwareConfig.cpp, HardwareConfig.h, main.cpp]
2026-03-04 feat: [Issue 11] Implement HTTPS POST request to AWS API and error handling
    [main.cpp]
2026-03-04 KiCadで回路図作成
    [ColorTimerNext.kicad_sch]
2026-03-04 無視リスト更新
2026-03-04 feat: [Issue 22] Add periodic serial status log showing state and LED color
    [main.cpp]
2026-03-04 fix: Add device_id param to API call and safe-guard items access
2026-03-04 回路図面Exportなど
2026-03-05 feat: [Issue 31] Add long press actions for configure mode and factory reset
    [main.cpp]
2026-03-05 chore: Fix PREF_API_KEY compilation error in test branch
    [HardwareConfig.cpp, HardwareConfig.h, main.cpp]
2026-03-05 fix: Resolve WiFiManager on-demand portal request handler routing issues
    [main.cpp]
2026-03-05 fix: Wait for shouldSaveConfig and properly reboot after on-demand portal exit
    [main.cpp]
2026-03-05 fix: Remove WiFi disconnect and enforce portal break to fix hang
    [main.cpp]
2026-03-05 fix: Ensure preferences are saved and applied correctly upon config portal exit
    [main.cpp]
2026-03-07 fix: validate tls certificates on esp32
    [main.cpp]
2026-03-07 fix: DynamoDB TTL を有効化する
2026-03-07 chore: backend デプロイスクリプトを追加する
2026-03-07 fix: 完全初期化で Preferences も消去する
    [main.cpp]
2026-03-07 feat: add USB-UART hardware schematic
    [ColorTimerNext.kicad_sch]
2026-03-08 feat: USB入力に逆流防止回路を追加する
    [ColorTimerNext.kicad_sch]
